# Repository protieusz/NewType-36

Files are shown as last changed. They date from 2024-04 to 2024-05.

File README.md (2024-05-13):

# NewType-36
NewType-36, a nowt36 variant with an integrated 25mm trackball, individual 36 RGBs & powered by WS RP2040 Zero

# Featured On KBD News
https://kbd.news/NewType-36-2358.html 

# Description
NewType-36, a modified [nowt36](https://github.com/tamago324/nowt36) that was originally designed by tamago324.
The following designs were modified by me and I got the blessing from tamago324 for the modifications:

-NewType-36 PCB was design by using the nowt36 pcb files as reference and EasyEDA was used to designed the NewType-36 to include a integrated PMW3360 trackball sensor.

-MCU changed from Pro Micron to Waveshare RP2040 Zero that is to be smd soldered onto the keyboard pcb.

-Heavily modifed case by Sato to have an integrated trackball holder module with an integrated 5mm thick switch plate.

-The case will have a notch cut out to display the solder MCU and exposed USB C connector of the MCU.

-The case consists of 2 pieces that is secured by having M2 screws in the hot inserts that are melted into the case.

-QMK source code was borrowed from bally by aki27 and the mod done was implement NewType-36's key matrix layout into [bally](https://github.com/aki27kbd/vial-qmk/tree/vial/keyboards/aki27/bally)'s code. No support will be giving for QMK questions. I just copy and pasted the code. For QMK support, it is best to ask QMK Discord Community.

-Warning: Print at your own risk. PCB print and build worked on my end. A lot of factors can happen during pcb manufacture, 3D printing, etc. Files are public so make use at your own risk.

# Status
PCBs received on Apr 26, 2024.  Assemble, soldered and build by me.

Currently the JLCPCB printed 5 PCBs are in transit and the case is already printed.
QMK source code complied into firmware and both of them were uploaded.

# Full Production Pictures























# Renders

Screenshot 2024-04-08 at 11 26 19 AM
Screenshot 2024-04-08 at 11 28 19 AM
Screenshot 2024-04-08 at 11 28 02 AM
Screenshot 2024-04-08 at 7 19 01 PM
Screenshot 2024-04-08 at 7 19 12 PM
Screenshot 2024-04-08 at 11 26 49 AM
Screenshot 2024-04-08 at 11 27 34 AM
Screenshot 2024-04-08 at 11 27 44 AM

# License
This work is available under the [Creative Commons Attribution 4.0 International License.](https://creativecommons.org/licenses/by/4.0/)
You are free to:

Share — copy and redistribute the material in any medium or format for any purpose, even commercially.
Adapt — remix, transform, and build upon the material for any purpose, even commercially.
The licensor cannot revoke these freedoms as long as you follow the license terms.

Attribution - You need to display the appropriate credit, provide a link to the license, and indicate whether the change has been made.

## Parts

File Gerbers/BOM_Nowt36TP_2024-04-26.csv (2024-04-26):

ID | Name | Designator | Footprint | Quantity | Manufacturer Part | Manufacturer | Supplier | Supplier Part | Price | link
1 | SN74LVC1T45QDCKRQ1 | U6 | SC-70-6_L2.0-W1.3-P0.65-LS2.1-BR | 1 | SN74LVC1T45QDCKRQ1 | TI(德州仪器) | LCSC | C139353 | 0.354 | https://lcsc.com/eda_search?q=C139353&%26type=1&ref=editor
2 | SK6812MINI-E_C5149201 | U13,U14,U15,U16,U17,U18,U19,U20,U21,U22,U23,U24,U25,U26,U27,U28,U29,U30,U31,U32,U33,U34,U35,U36,U37,U38,U39,U40,U41,U42,U43,U44,U45,U46,U47,U48 | LED-SMD_L3.2-W2.8-TR | 36 | SK6812MINI-E | 欧思科光电 | LCSC | C5149201 | 0.167 | https://lcsc.com/eda_search?q=C5149201&%26type=1&ref=editor
3 | DIODE-SOD123 | D000,D001,D002,D003,D004,D005,D006,D007,D008,D009,D304,D302,D305,D307,D100,D101,D102,D103,D104,D105,D106,D107,D108,D109,D200,D201,D202,D203,D204,D205,D206,D207,D208,D209,D303,D306 | DIODE-SOD123 | 36
4 | 4.7uF | C17,C19,C20 | C0402 | 3 | CL05A475MP5NRNC | SAMSUNG(三星) | LCSC | C23733 | 0.005 | https://lcsc.com/eda_search?q=C23733&%26type=1&ref=editor
5 | 100nF | C18 | C0402 | 1 | CL05B104KB54PNC | SAMSUNG(三星) | LCSC | C307331 | 0.005 | https://lcsc.com/eda_search?q=C307331&%26type=1&ref=editor
6 | 10kΩ | R10,R12,R13 | R0402 | 3 | 0402WGF1002TCE | UNI-ROYAL(厚声) | LCSC | C25744 | 0.001 | https://lcsc.com/eda_search?q=C25744&%26type=1&ref=editor
7 | 39Ω | R11 | R0402 | 1 | 0402WGJ0390TCE | UNI-ROYAL(厚声) | LCSC | C25164 |  | https://lcsc.com/eda_search?q=C25164&%26type=1&ref=editor
8 | 15kΩ | R14 | R0402 | 1 | 0402WGF1502TCE | UNI-ROYAL(厚声) | LCSC | C25756 | 0.001 | https://lcsc.com/eda_search?q=C25756&%26type=1&ref=editor
9 | AP2127K-ADJTRG1 | U10 | SOT-23-5_L3.0-W1.7-P0.95-LS2.8-BR | 1 | AP2127K-ADJTRG1 | DIODES(美台) | LCSC | C96343 | 0.071 | https://lcsc.com/eda_search?q=C96343&%26type=1&ref=editor
10 | PMW3360DM-T2QU | U11 | PMW3360DM-T2QU.PACK | 1 | PMW3360DM-T2QU |  |  |  |  | http://www.pixart.com/upload/PMS0058-PMW3360DM-T2QU-NNDS-R1.30-06042016_20160902201411.pdf
11 | RP2040-ZERO_WAVESHARE - with GPIO | U1 | RP2040-ZERO_WAVESHARE- W/ GPIO | 1
12 | Switch | K000,K001,K002,K003,K004,K005,K006,K007,K008,K009,K100,K101,K102,K103,K104,K105,K106,K107,K108,K109,K200,K201,K202,K203,K204,K205,K206,K207,K208,K209,K302,K303,K304,K305,K306,K307 | CHERRY_MX_100_MILLMAX | 36

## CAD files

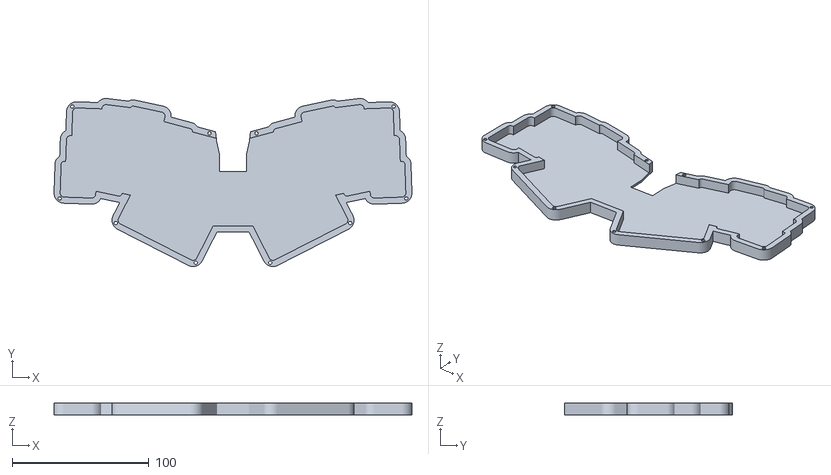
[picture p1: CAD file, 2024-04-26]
NewType Case STL/NewType Bottom.stl
261.7 x 122.8 x 8.60

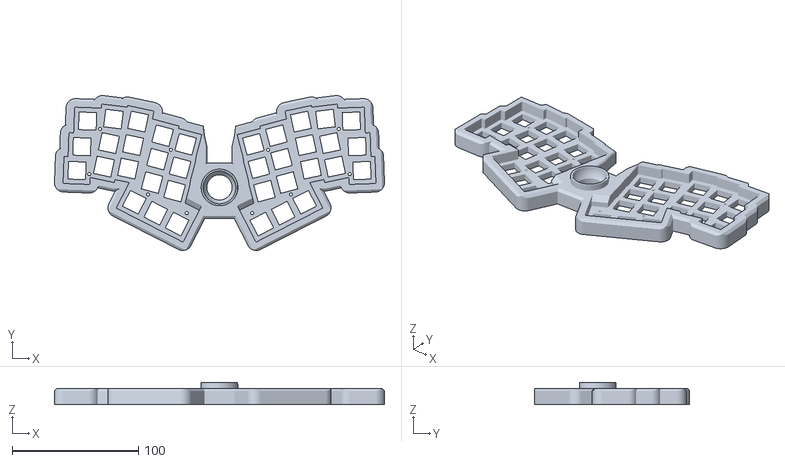
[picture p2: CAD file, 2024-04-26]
NewType Case STL/NewTypeTopCase.stl
261.7 x 122.8 x 17.8

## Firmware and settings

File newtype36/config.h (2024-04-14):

// Copyright 2024 ProtieusKeebs
// SPDX-License-Identifier: GPL-2.0-or-later

#pragma once

//#define VIAL_KEYBOARD_UID {0xC4, 0x18, 0xCC, 0x6D, 0x1C, 0x16, 0x5B, 0x8D}
//#define VIAL_UNLOCK_COMBO_ROWS {0, 0}
//#define VIAL_UNLOCK_COMBO_COLS {1, 11}

/* VIA */
//#define DYNAMIC_KEYMAP_LAYER_COUNT 8


/* key matrix size */
//#define MATRIX_COLS 13
//#define MATRIX_ROWS 4


/* tapping term */
// #define TAPPING_FORCE_HOLD
//#define TAPPING_TERM 200
// #define IGNORE_MOD_TAP_INTERRUPT

#define RP2040_BOOTLOADER_DOUBLE_TAP_RESET // Activates the double-tap behavior
#define RP2040_BOOTLOADER_DOUBLE_TAP_RESET_TIMEOUT 200U // Timeout window in ms in which the double tap can occur.

#ifdef COMBO_ENABLE
#    define COMBO_COUNT 2
#    define COMBO_TERM 200
#endif

/* Encoder */
//#define ENCODERS_PAD_A { GP11 }
//#define ENCODERS_PAD_B { GP12 }
//#define ENCODER_RESOLUTION 4

/* Matrix*/
//#define MATRIX_COL_PINS { GP25, GP24, GP23, GP22, GP21, GP26, GP27, GP20, GP19, GP18, GP17, GP16, GP13 }
//#define MATRIX_ROW_PINS { GP28, GP10, GP14, GP15 }

/* COL2ROW, ROW2COL */
//#define DIODE_DIRECTION COL2ROW


/* Set 0 if debouncing isn't needed */
//#define DEBOUNCE 5


/* Mechanical locking support. Use KC_LCAP, KC_LNUM or KC_LSCR instead in keymap (Very Important for Scroll Lock!!!) */
#undef LOCKING_SUPPORT_ENABLE
/* Locking resynchronize hack */
#undef LOCKING_RESYNC_ENABLE


/* RGB LED */
//#define WS2812_PIO_USE_PIO1
#define WS2812_DI_PIN GP0

#ifdef RGBLIGHT_ENABLE
    #define RGBLIGHT_LED_COUNT 36
    #define RGBLIGHT_LIMIT_VAL 80
    #define RGBLIGHT_HUE_STEP 10
    #define RGBLIGHT_SAT_STEP 17
    #define RGBLIGHT_VAL_STEP 17

    #define RGBLIGHT_EFFECT_BREATHING
    #define RGBLIGHT_EFFECT_RAINBOW_MOOD
    #define RGBLIGHT_EFFECT_RAINBOW_SWIRL
    #define RGBLIGHT_EFFECT_SNAKE
    #define RGBLIGHT_EFFECT_KNIGHT
    #define RGBLIGHT_EFFECT_CHRISTMAS
    #define RGBLIGHT_EFFECT_STATIC_GRADIENT
    #define RGBLIGHT_EFFECT_TWINKLE
    #define RGBLIGHT_EFFECT_ALTERNATING
#endif


/* Trackball */

#ifdef POINTING_DEVICE_ENABLE

//#    undef RP_SPI_USE_SPI0
//#    define RP_SPI_USE_SPI0 TRUE
//#    undef RP_SPI_USE_SPI1
//#    define RP_SPI_USE_SPI1 FALSE
#    define SPI_DRIVER SPID1

//#    define SPI_SCK_PIN GP22 //6
//#    define SPI_MISO_PIN GP24 //4
//#    define SPI_MOSI_PIN GP23 //7
#    define SPI_SCK_PIN GP14
#    define SPI_MISO_PIN GP12
#    define SPI_MOSI_PIN GP15

#endif


#ifndef PMW33XX_CS_PIN
#    define PMW33XX_CS_PIN GP13
#endif
//#define POINTING_DEVICE_INVERT_X
//#define POINTING_DEVICE_INVERT_Y
//#define ROTATIONAL_TRANSFORM_ANGLE 90
//#define POINTING_DEVICE_ROTATION_90

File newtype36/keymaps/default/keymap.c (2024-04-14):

/*
Copyright 2024 ProtieusKeebs

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
You should have received a copy of the GNU General Public License
along with this program.  If not, see <http://www.gnu.org/licenses/>.
*/

#include QMK_KEYBOARD_H

enum combo_events {
  COMBO_DEL,
  COMBO_ESC,
  //COMBO_RCLICK,
  COMBO_LENGTH
};
uint16_t COMBO_LEN = COMBO_LENGTH;

const uint16_t PROGMEM combo_del[] = {KC_Y, KC_H, COMBO_END};
const uint16_t PROGMEM combo_esc[] = {KC_T, KC_G, COMBO_END};
//const uint16_t PROGMEM combo_rclick[] = {KC_MS_BTN1, SCRL_MO, COMBO_END};

combo_t key_combos[] = {
  [COMBO_DEL] = COMBO(combo_del, KC_DEL),
  [COMBO_ESC] = COMBO(combo_esc, KC_ESC),
  //[COMBO_RCLICK] = COMBO(combo_rclick, KC_MS_BTN2),
};

layer_state_t layer_state_set_user(layer_state_t state) {
    return update_tri_layer_state(state, 1, 2, 3);
} 

enum layer_names {
  _BASE,
  _FN1,
  _FN2,
  _FN3
};

const uint16_t PROGMEM keymaps[][MATRIX_ROWS][MATRIX_COLS] = {
    
    [_BASE] = LAYOUT(
        KC_Q,         KC_W, KC_E,    KC_R,    KC_T,                  KC_Y,          KC_U,          KC_I,     KC_O,   KC_P,
        KC_A,         KC_S, KC_D,    KC_F,    KC_G,                  KC_H,          KC_J,          KC_K,     KC_L,   KC_SCLN,
        LSFT_T(KC_Z), KC_X, KC_C,    KC_V,    KC_B,                  KC_N,          KC_M,          KC_COMMA, KC_DOT, RSFT_T(KC_SLSH),
                            KC_LGUI, KC_LCTL, LT(1,KC_BSPC),         LT(2,KC_SPC),  KC_ENT,        KC_LALT
    ),
    [_FN1] = LAYOUT(
        KC_1,    KC_2,    KC_3,    KC_4,    KC_5,                    KC_6,     KC_7,    KC_8,    KC_9,    KC_0,
        KC_TAB,  _______, KC_MUTE, KC_VOLD, KC_VOLU,                 KC_MINS,  KC_EQL,  KC_LBRC, KC_RBRC, KC_QUOT,
        _______, SCRL_MO, KC_MS_BTN2,KC_MS_BTN1, _______,            KC_TILD,  KC_GRV,  _______, _______, KC_BSLS,
                          _______, _______, _______,                 _______,  _______, _______
    ),
    [_FN2] = LAYOUT(
        KC_EXLM, KC_AT,   KC_HASH, KC_DLR,  KC_PERC,                 KC_CIRC,  KC_AMPR, KC_ASTR, KC_LPRN, KC_RPRN,
        RGB_VAI, RGB_SAI, RGB_HUI, RGB_SPI, RGB_MOD,                 RGB_TOG,  _______, _______, _______, _______,
        RGB_VAD, RGB_SAD, RGB_HUD, RGB_SPD, RGB_RMOD,                _______,  _______, _______, _______, _______,
                          _______, _______, _______,                 _______,  _______, _______
    ),
    [_FN3] = LAYOUT(
        _______, KC_UP, _______, _______, _______,                   KC_F1,   KC_F2,   KC_F3,   KC_F4,   KC_PSCR,
        KC_LEFT, KC_DOWN, KC_RIGHT, _______, _______,                KC_F5,   KC_F6,   KC_F7,   KC_F8,   KC_F9,
        _______, _______, ROT_L15, ROT_R15, CPI_SW,                  KC_F10,  KC_F11,  KC_F12,  _______, _______,
                          _______, _______, _______,                 _______, _______, _______
    )
};

//bool encoder_update_user(uint8_t index, bool clockwise) {
    //if (index == 0) {
        //if (clockwise) {
            //tap_code(KC_VOLD);
            //tap_code(KC_MS_WH_UP);
        //} else {
            //tap_code(KC_VOLU);
            //tap_code(KC_MS_WH_DOWN);
        //}
    //}
    //return true;
//}

//#if defined(ENCODER_MAP_ENABLE)
//const uint16_t PROGMEM encoder_map[][NUM_ENCODERS][2] = {
    //[0] =  { ENCODER_CCW_CW(KC_MS_WH_UP, KC_MS_WH_DOWN)  },
    //[1] =  { ENCODER_CCW_CW(KC_MS_WH_LEFT, KC_MS_WH_RIGHT)  },
    //[2] =  { ENCODER_CCW_CW(KC_PGUP, KC_PGDN)  },
    //[3] =  { ENCODER_CCW_CW(KC_VOLD, KC_VOLU)  } 
    //[4] =  { ENCODER_CCW_CW(XXXXXXX, XXXXXXX) }
//};
//#endif

//keyevent_t encoder1_ccw = {
    //.key = (keypos_t){.row = 3, .col = 0},
    //.pressed = false
//};

//keyevent_t encoder1_cw = {
    //.key = (keypos_t){.row = 3, .col = 9},
    //.pressed = false
//};

//bool encoder_update_user(uint8_t index, bool clockwise) {
    //if (index == 0) { /* First encoder */
        //if (clockwise) {
            //encoder1_cw.pressed = true;
            //encoder1_cw.time = (timer_read() | 1);
            //action_exec(encoder1_cw);
        //} else {
            //encoder1_ccw.pressed = true;
            //encoder1_ccw.time = (timer_read() | 1);
            //action_exec(encoder1_ccw);
        //}
    //}

    //return true;
//}

//void matrix_scan_user(void) {

    //if (IS_PRESSED(encoder1_ccw)) {
        //encoder1_ccw.pressed = false;
        //encoder1_ccw.time = (timer_read() | 1);
        //action_exec(encoder1_ccw);
    //}

    //if (IS_PRESSED(encoder1_cw)) {
        //encoder1_cw.pressed = false;
        //encoder1_cw.time = (timer_read() | 1);
        //action_exec(encoder1_cw);
    //}

//}

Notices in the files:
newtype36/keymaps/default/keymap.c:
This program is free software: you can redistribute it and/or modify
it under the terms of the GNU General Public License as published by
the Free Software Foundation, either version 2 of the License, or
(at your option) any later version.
